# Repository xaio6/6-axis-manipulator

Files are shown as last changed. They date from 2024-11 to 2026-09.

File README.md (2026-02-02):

 # 听懂人话的6轴Agent机械臂（H1）

<h1 align="center">3D打印版本</h1>

## 简介
<div align="center">
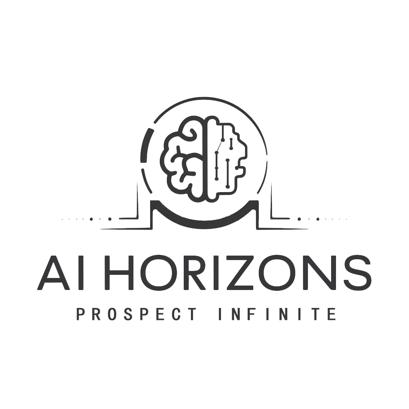
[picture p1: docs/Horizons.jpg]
<br>
</div>

> [!IMPORTANT]
>
> 🔆 该项目也在持续的更新阶段，如果您有任何关于新的模型方法、研究、技术或发现运行错误的建议，请随时编辑并提交 PR。⭐ 如果您发现这个Github Project有用，请给它点个星！🤩🤩

# 控制源码

> 全部源码跟算法在这个[仓库](https://github.com/xaio6/Embodied_Arm)

### 注意事项
- 具体组装跟控制流程，请详细阅读[机械臂组装流程.pdf](./机械臂组装流程-新.pdf)

## 演示

具体演示查看[bilbil](https://www.bilibili.com/video/BV12sSEBQEbQ/?spm_id_from=333.1387.homepage.video_card.click)

<div align="center">
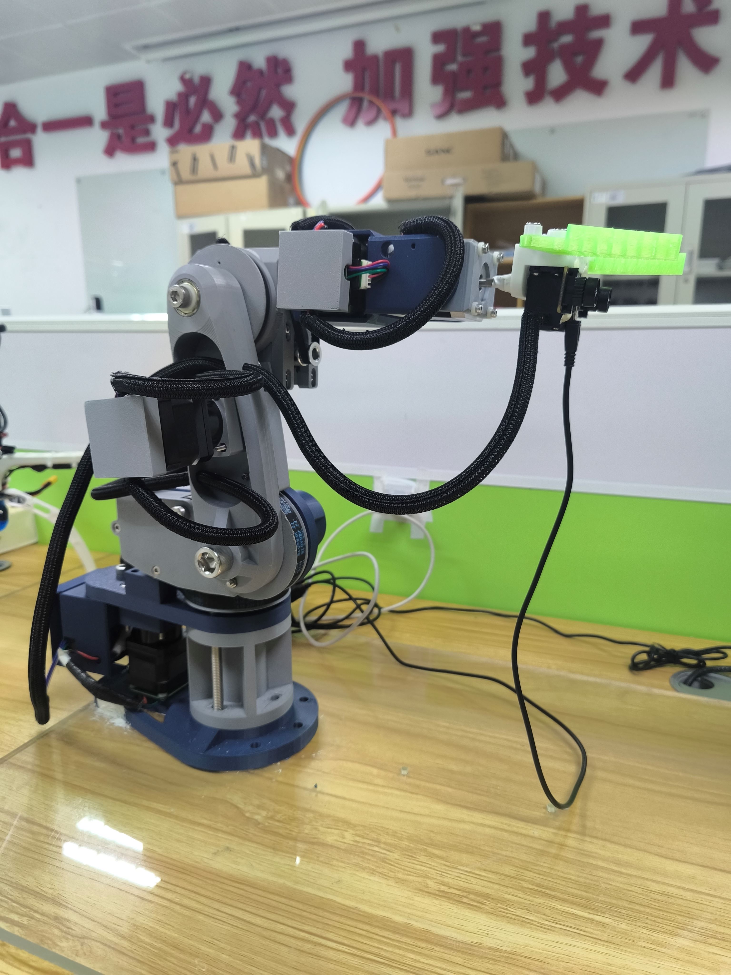
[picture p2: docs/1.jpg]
<br>
</div>

<div align="center">
<br>
</div>

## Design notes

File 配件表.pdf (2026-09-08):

# 机械臂链接螺丝螺母轴承基本配件

对应店铺 (https://item.taobao.com/item.htm?ft=t&id=909249087823&spm=a21dvs.23580594.0.0.4fee2c1bhwSzJX)

### M14 规格

种类 | 规格 | 数量 | 备注

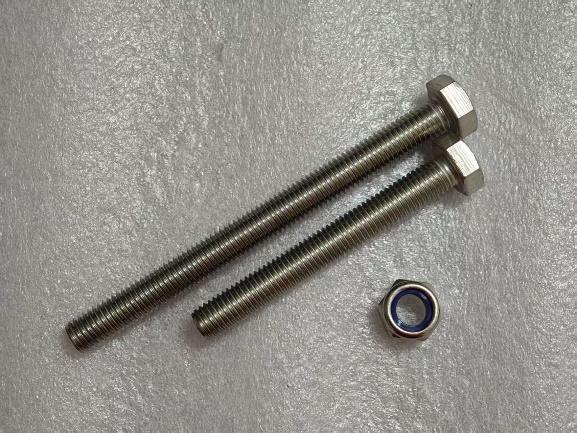
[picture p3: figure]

M14 螺丝(外六角) | 160MM | 1 | 基座之间链接
| 110MM | 1 | 2 座与 3 座之间 链接
M14 螺母 | 带防滑 | 2

### M8 规格

M8 螺丝(内六角) | 100MM | 4 | 基座之间连接
| 35MM | 2 | 2 轴盖子连接跟 电源仓
| 90MM | 1 | 3 轴座与 4 轴座 之间链接
| 80MM | 1 | 4 轴座与 5 轴座 之间链接
M8 螺母 | 加厚 | 8

### M4 规格

M4 螺丝(内六角) | 35MM | 8 | 1 轴和 2 轴减速 器连接块与轴 座之间连接
| 22mm | 4 | 2 轴基座与 2 轴 齿轮之间连接

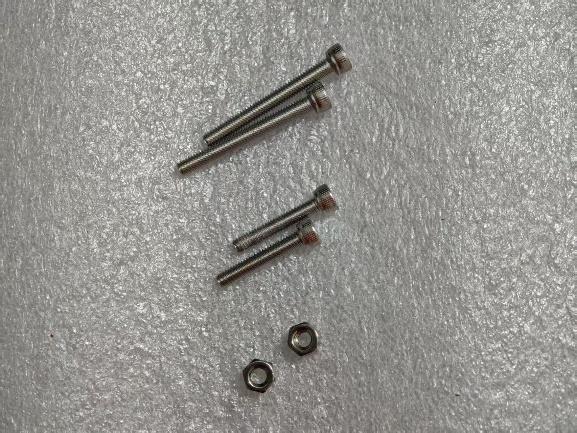
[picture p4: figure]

M4 螺母 | 加厚 | 12

### M3 规格

M3 螺丝(内六角) | 35MM | 36 | 3 轴和 4 轴和 5 轴减速器连接 块与轴座之间 连接
| 8MM | 24 | 减速器与连接 块之间连接以 及末端电机连 接
| 25MM | 4 | 一轴压同步带 块固定
| 15MM | 2 | 一轴压同步带 块固定
M3 螺母 | 加厚 | 42

### 塑料垫片

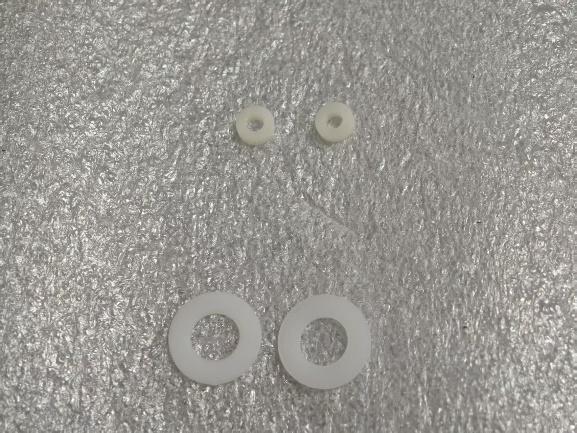
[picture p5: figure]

ABS 垫高柱 | M3*7*1（或者 M3*7*2） | 24 | 一轴压同步带 块轴承垫片以 及驱动板跟电 机连接处
塑胶尼龙垫片 | M8*16*1.5 | 4 | 轴承之间垫片

轴承

轴承 | 623zz | 4

一轴压同步带
块所需

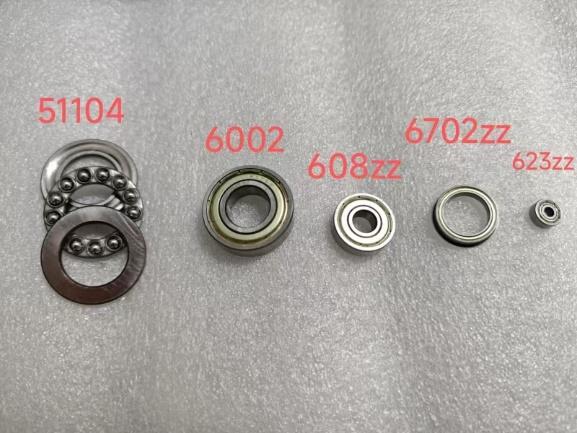
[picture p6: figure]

608zz | 8
6702zz | 3
6002 | 4
51104 | 2

# 电机所需配件

### 同步轮

种类 | 规格 | 数量 | 备注
同步轮 | 2gt、齿 20、宽 6、内孔 8 | 3 | 3 轴 4 轴 5 轴同 步带轮
| 3M、齿 16、宽 10、孔 8 | 2 | 1，2 轴同步带 轮

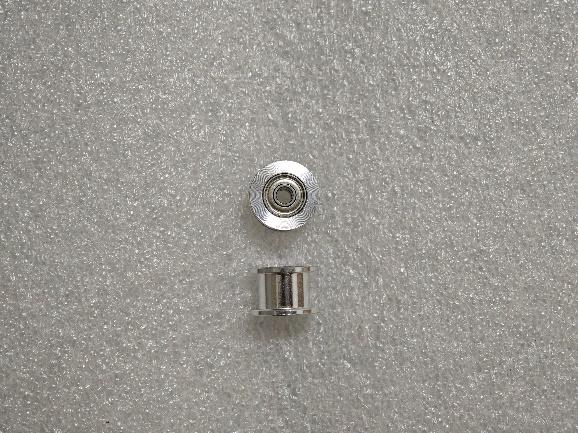
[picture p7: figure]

| 2gt、惰轮、宽 6、齿 16(无齿) | 2 | 盖子与 3 轴连杆 之间

### 同步带

同步带 | 3M、宽 10、长 315 | 1 | 1 轴同步带

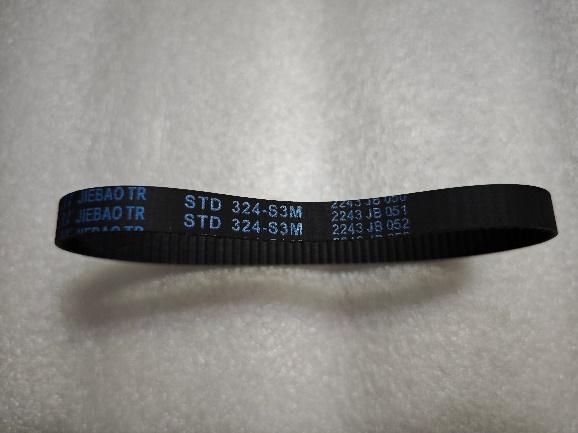
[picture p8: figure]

| 3M、宽 10、长 324 | 1 | 2 轴同步带

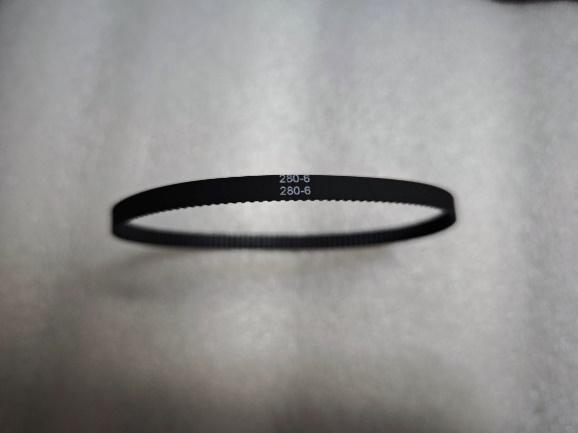
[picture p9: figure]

| 2gt、宽 6、长 280 | 1 | 3 轴同步带
| 2gt、宽 6、长 180(或者 174） | 1 | 4 轴同步带

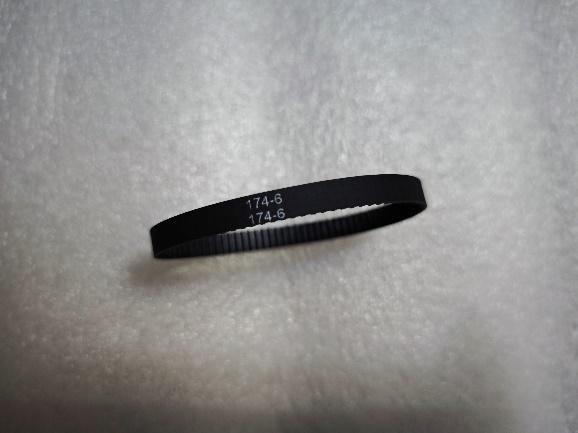
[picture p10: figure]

2gt、宽 6、长
176(或者 174）
1 | 5 轴同步带

### 电机配件

径向磁铁 | 直径 4 高度 4 | 6

### 磁编码器所 需磁铁

电机

种类 | 规格 | 型号 | 备注

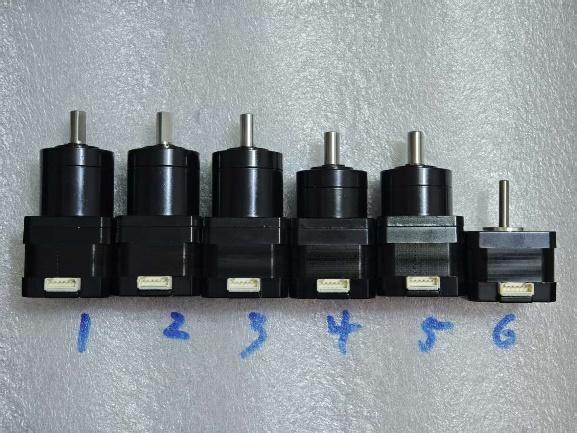
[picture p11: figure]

一轴 | 1:27 | 42HS34 | 一轴
二轴 | 1:27 | 42HS34 | 二轴
三轴 | 1:14 | 42HS34 | 三轴
四轴 | 5.18:1 | 42HS34 | 四轴
五轴 | 5.18:1 | 42HS34 | 五轴
六轴 | 34 高度 | 42BYGHS34S | 六轴

# 电机驱动

种类 | 规格 | 数量 | 备注

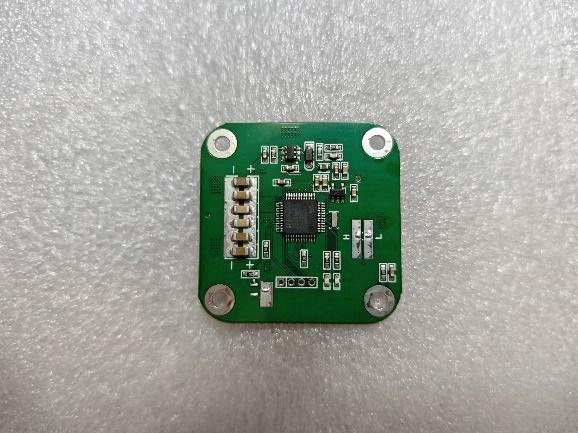
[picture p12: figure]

CAN 闭环步进驱动板 | 12V | 6 | 建议多买一块
USB 转 CAN 板 | | 1

电源

种类 | 规格 | 数量 | 备注

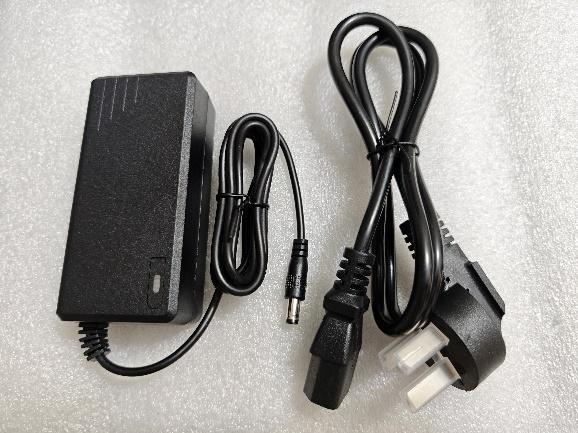
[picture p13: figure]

12V3A 稳定电源 | 12V3A | 1

母头线 | DC 单母头线 | 1

# 视觉抓取

种类 | 规格 | 数量 | 备注

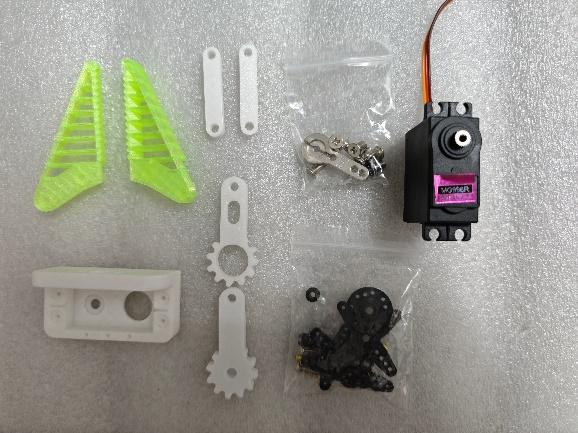
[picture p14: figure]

机械臂柔性软夹子 | | 1 | 机械臂柔性软夹 子

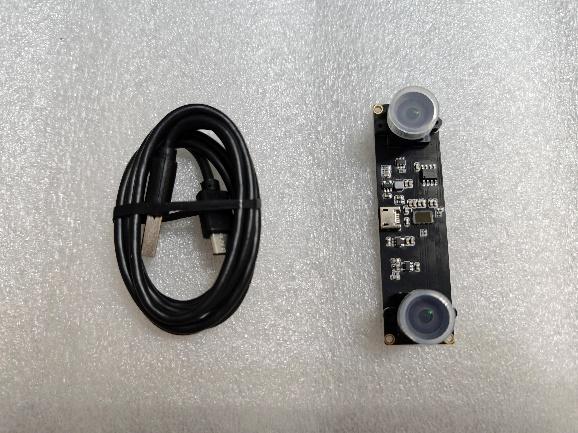
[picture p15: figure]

100 万像素双目相机 | 105°无畸变 /2.4mm | 1 | 100 万像素双目 相机

ESP32 | 带 5V 针脚 | 1 | 最好 type-c 口

# 3D 打印模型外壳

## 有提供 sw 模型，可以自行进行打印

对应店铺 (https://item.taobao.com/item.htm?ft=t&id=909249087823&spm=a21dvs.23580594.0.0.4fee2c1bhwSzJX)

名称 | 数量件/套

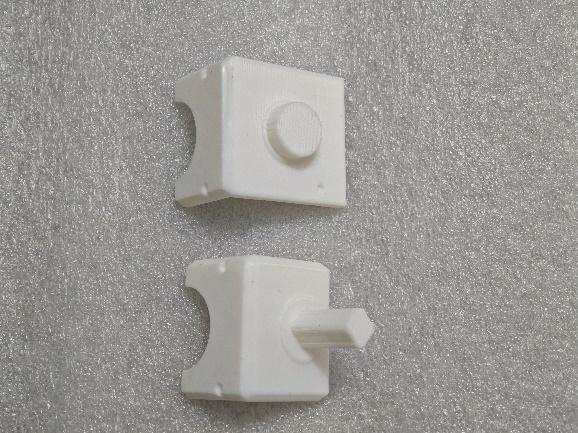
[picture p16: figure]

42_J6_kotelo | 1
Pulley32TGT2 | 1

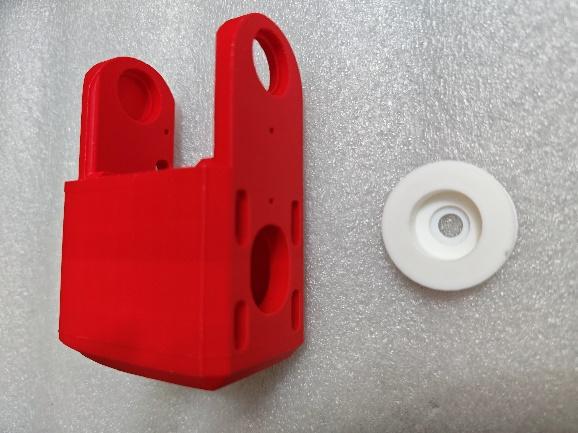
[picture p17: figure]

42 末端 Pulley60Tv2 | 1

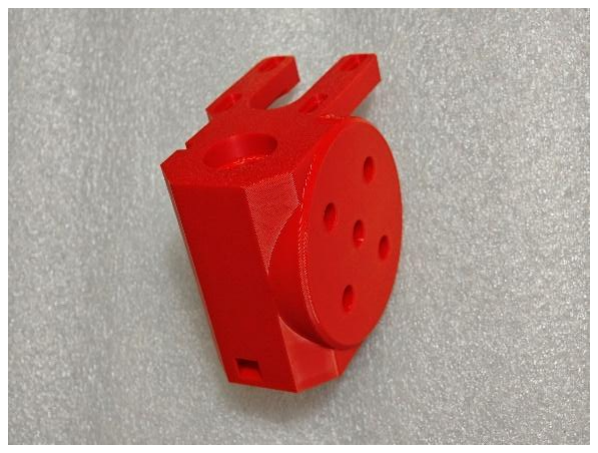
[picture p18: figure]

Arm2Mountv2 | 1
Pulley100Tv5 | 1

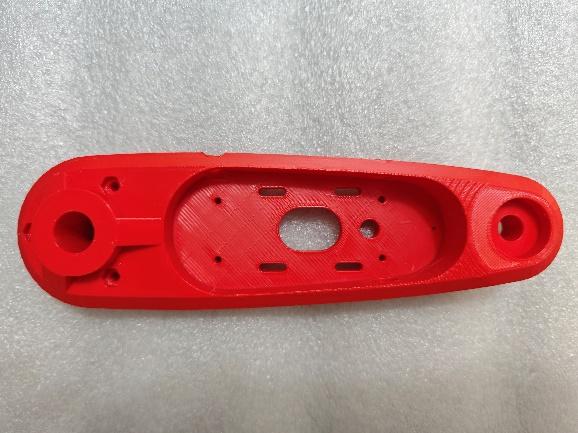
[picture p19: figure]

Arm1v2 | 1

Arm 2.3 | 1

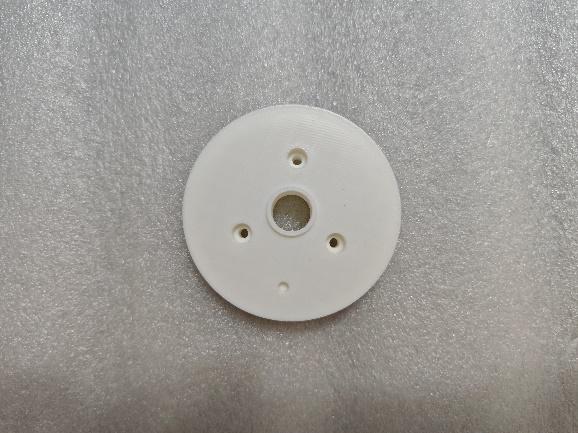
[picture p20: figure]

HTD3M 80T | 1

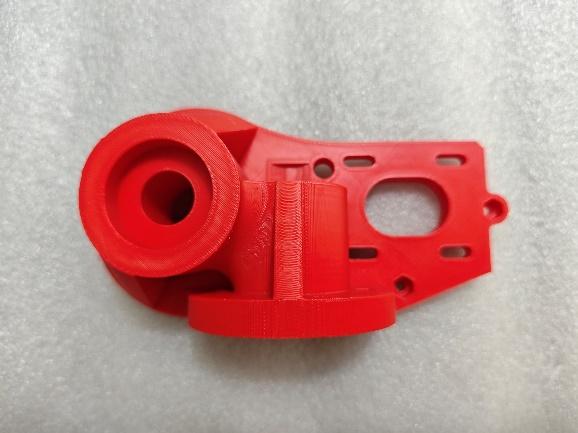
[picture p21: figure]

BaseWall_2_v2 | 1
Basewall cover v2 | 1

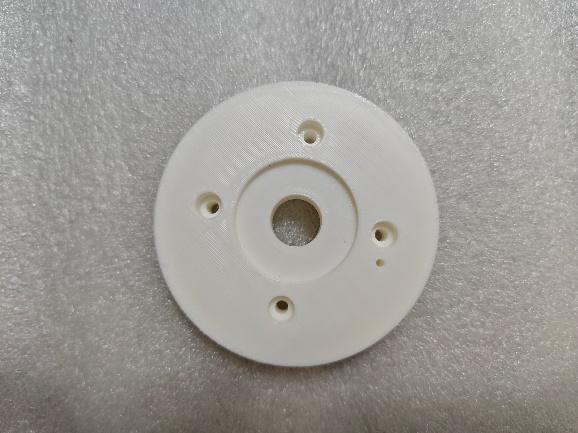
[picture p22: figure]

HTD3M 80T_base | 1
Baseplate | 1

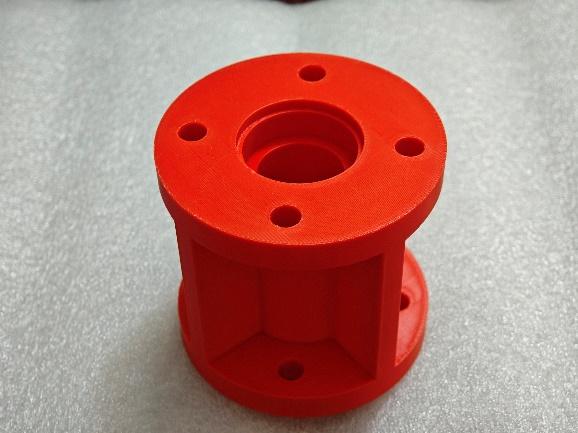
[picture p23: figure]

Bottom Tube | 1

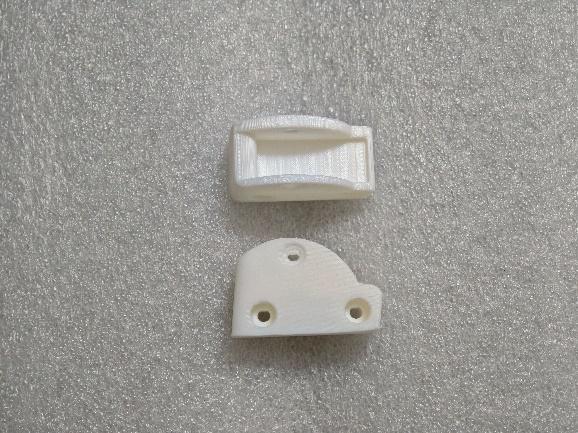
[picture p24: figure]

压同步轮带盖 | 1

Bottom support | 1

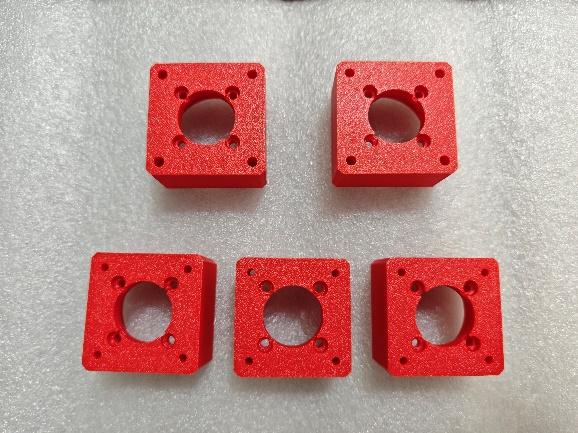
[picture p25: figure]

Motor spacer | 1
电机后盖 | 1

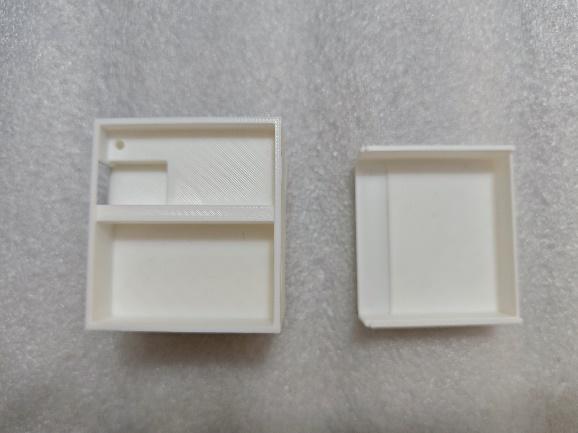
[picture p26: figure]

电源仓 | 1

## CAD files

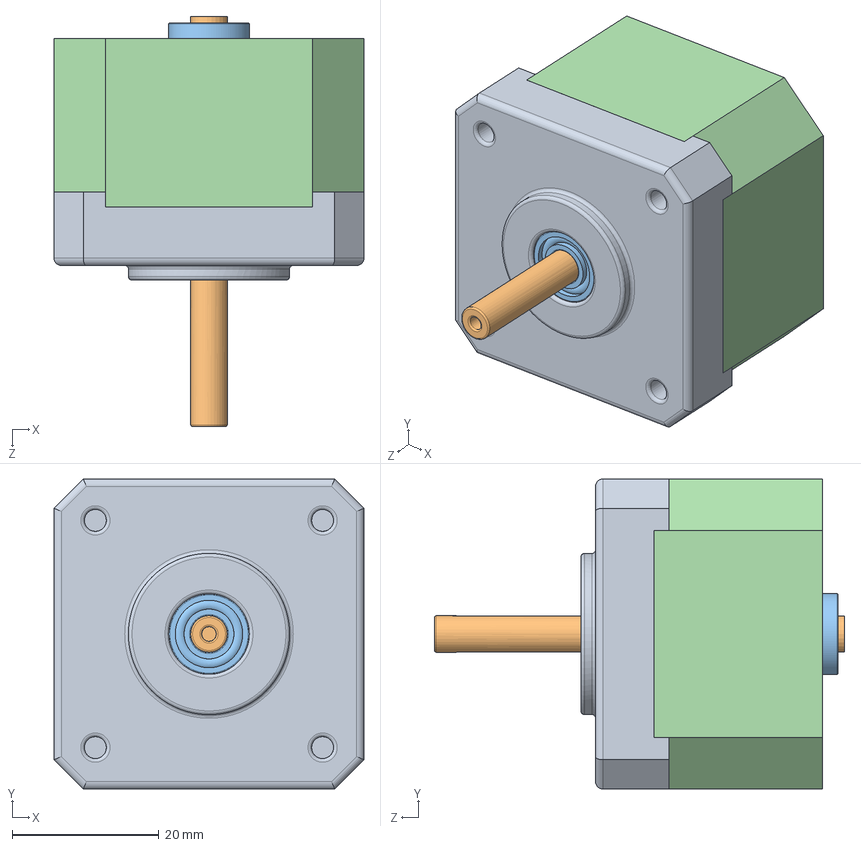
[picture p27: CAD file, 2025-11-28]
Arm_Model/stepper-motor-nema-17.snapshot.17/NEMA 17 kiinalaiset.SLDASM
42.3 x 42.3 x 56.0 mm
Tapa
Eje
instrument ball bearing_68_am x 2
零件2^NEMA 17 kiinalaiset

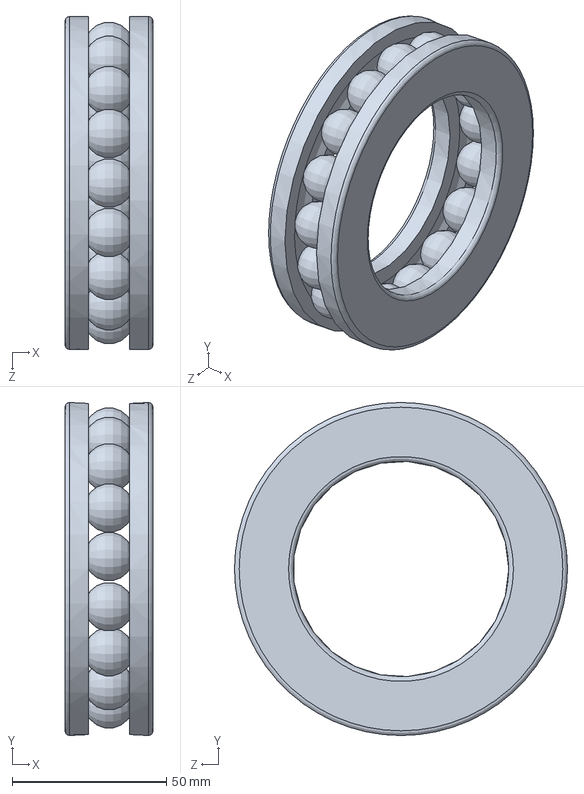
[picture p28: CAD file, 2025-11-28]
Arm_Model/ball bearings/thrust ball bearing_68_iso.sldprt
28.6 x 108.0 x 108.0 mm

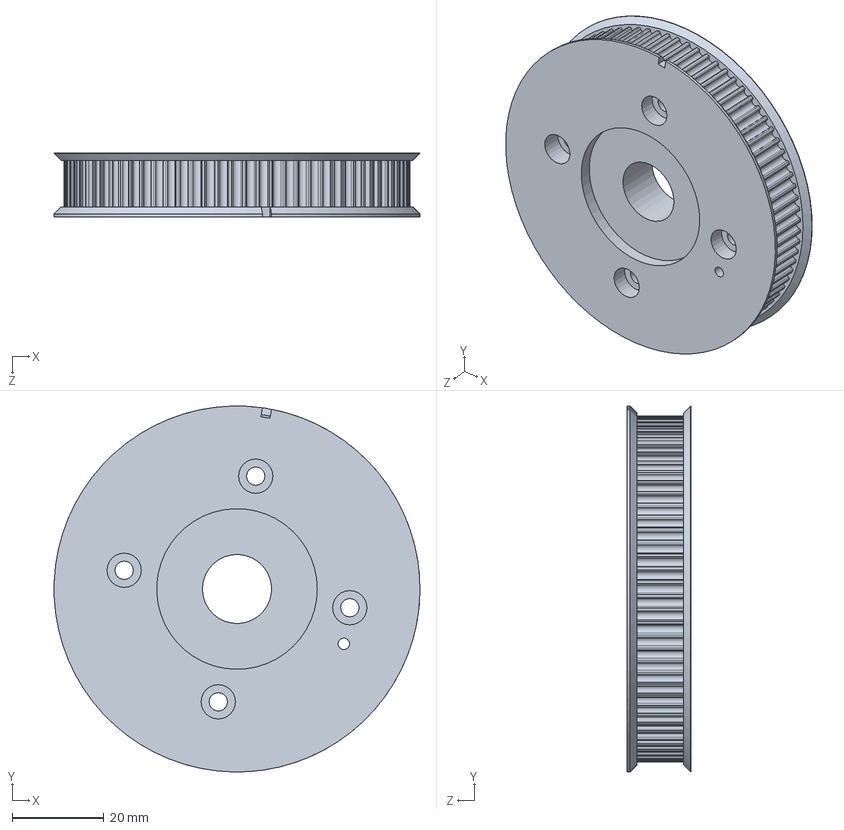
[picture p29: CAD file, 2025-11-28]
Arm_Model/Solidworks/HTD3M 80T_base.SLDPRT
80.0 x 80.0 x 14.0 mm

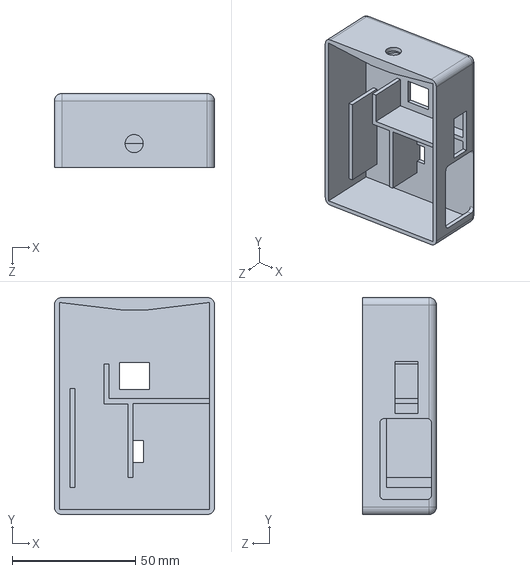
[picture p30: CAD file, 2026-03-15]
Arm_Model/后仓.SLDPRT
65.0 x 88.0 x 30.0 mm

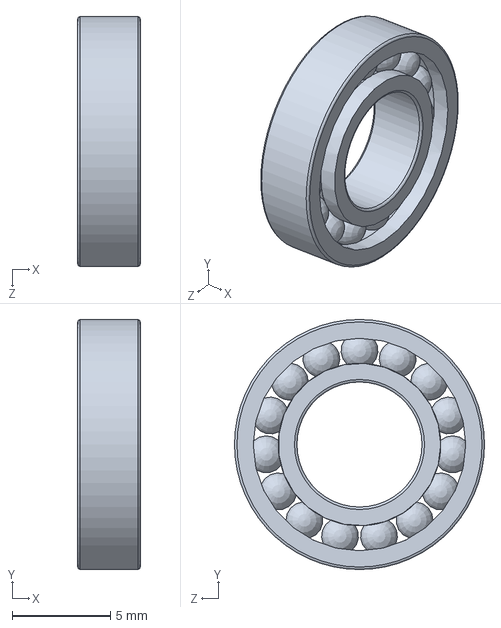
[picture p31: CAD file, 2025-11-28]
Arm_Model/ball bearings/instrument ball bearing_68_am.sldprt
3.17 x 12.7 x 12.7 mm

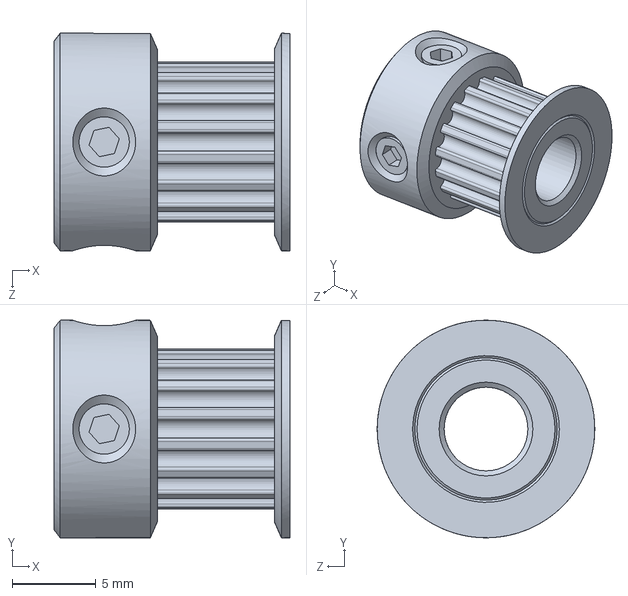
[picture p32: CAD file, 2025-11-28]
Arm_Model/Solidworks/GT2_16T_13x14.SLDPRT
14.1 x 13.0 x 13.0 mm

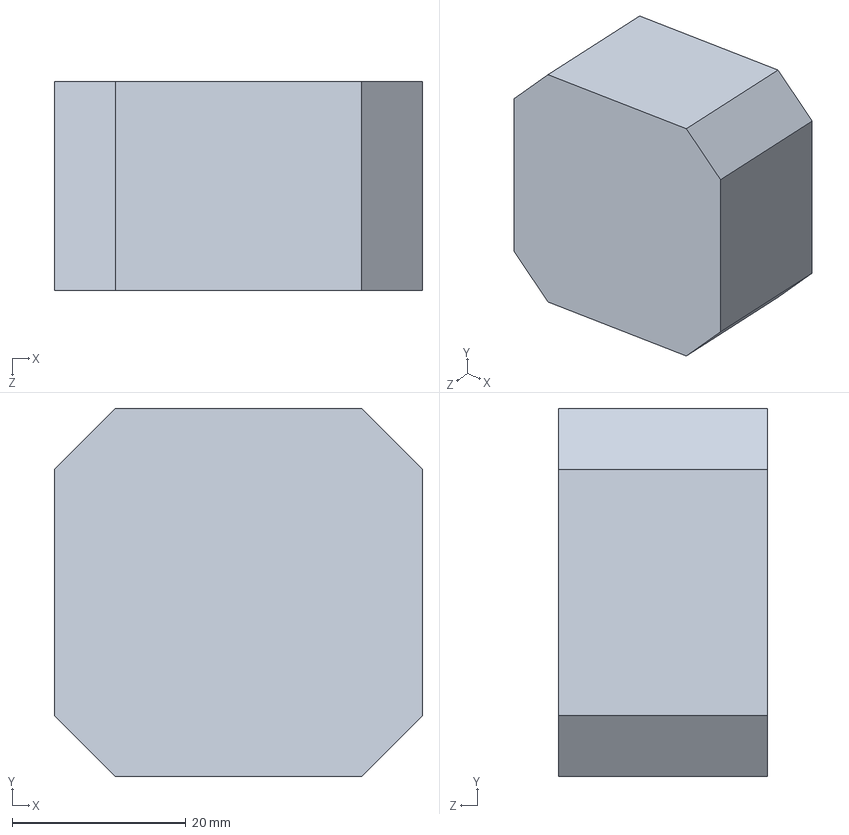
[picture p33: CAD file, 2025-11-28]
Arm_Model/stepper-motor-nema-17.snapshot.17/Cuerpo.SLDPRT
42.3 x 42.3 x 24.0 mm

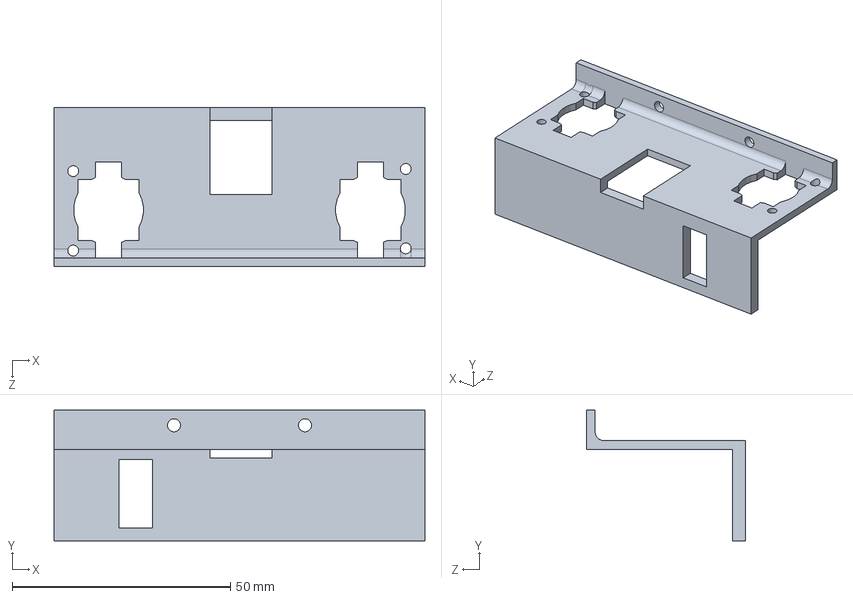
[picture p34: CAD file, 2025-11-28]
Arm_Model/前脸.SLDPRT
85.0 x 30.0 x 36.5 mm

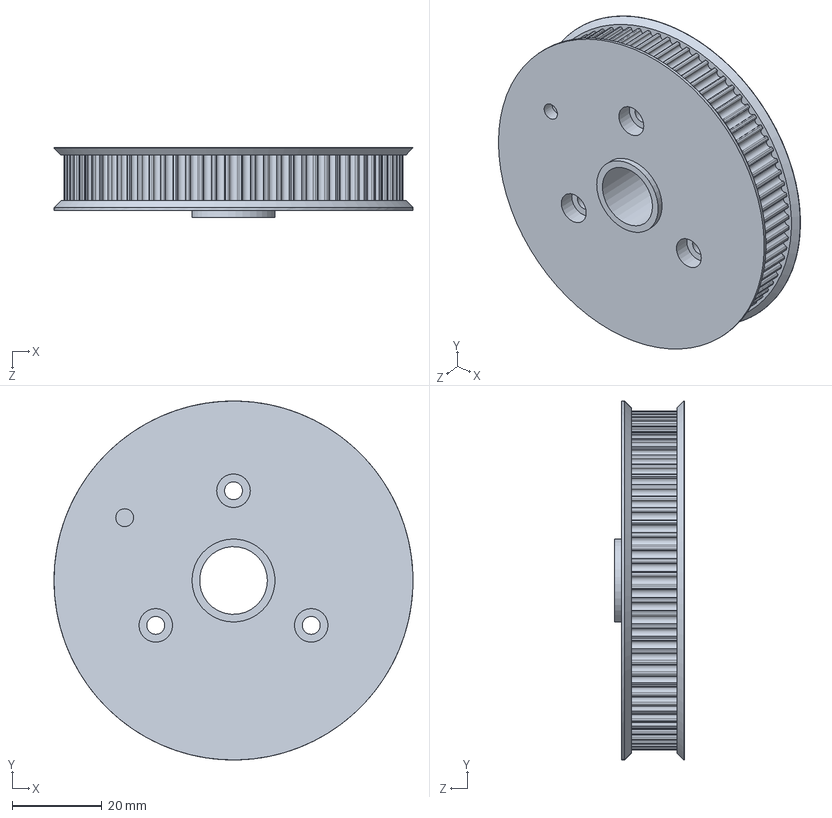
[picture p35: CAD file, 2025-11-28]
Arm_Model/Solidworks/HTD3M 80T.SLDPRT
80.0 x 80.0 x 15.5 mm

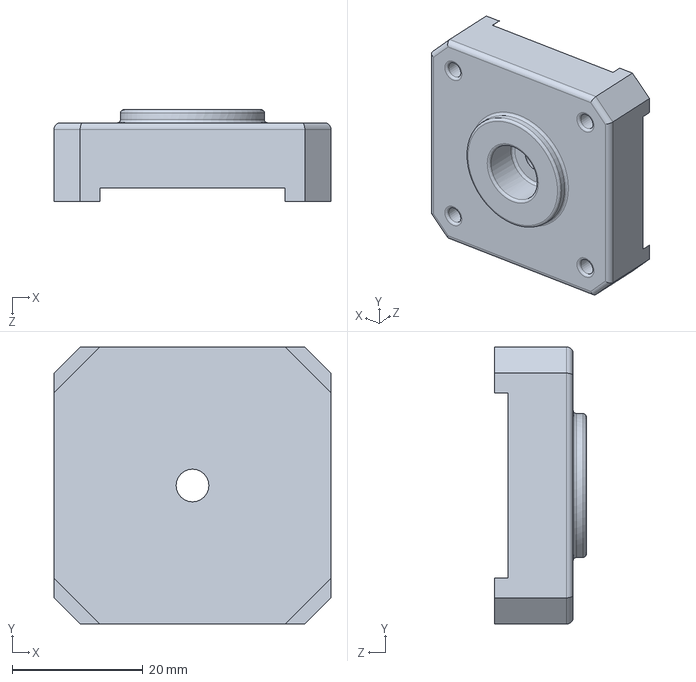
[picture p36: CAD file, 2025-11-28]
Arm_Model/stepper-motor-nema-17.snapshot.17/Tapa.SLDPRT
42.3 x 42.3 x 14.0 mm

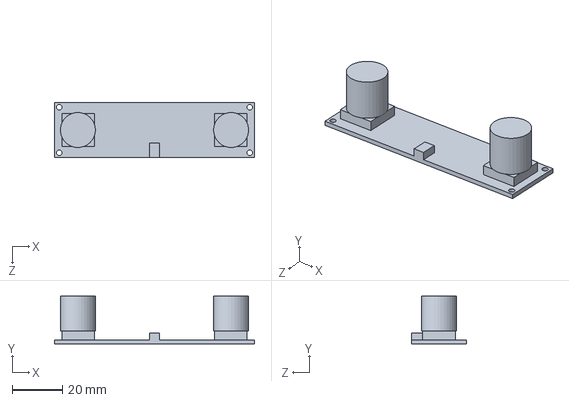
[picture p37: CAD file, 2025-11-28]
Arm_Model/相机.SLDPRT
80.0 x 19.1 x 22.0 mm

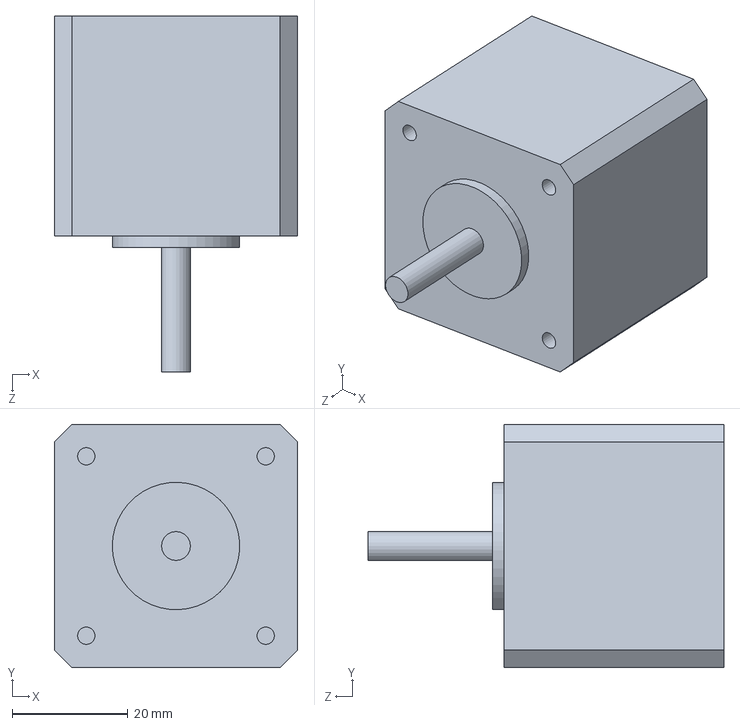
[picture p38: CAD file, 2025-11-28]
Arm_Model/Solidworks/Nema 14 stepper.SLDPRT
42.0 x 42.0 x 61.5 mm

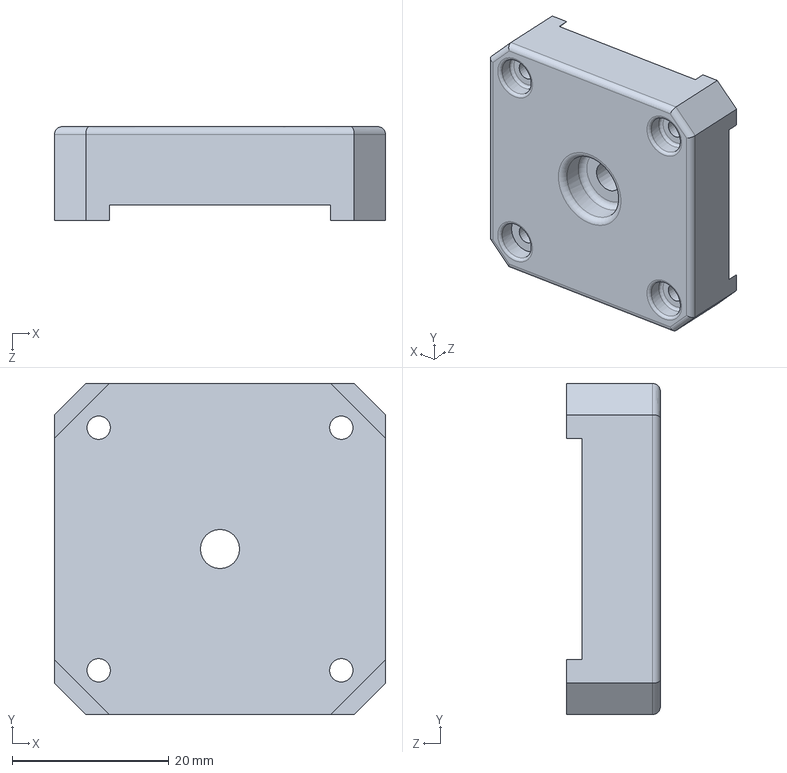
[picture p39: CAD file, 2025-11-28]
Arm_Model/stepper-motor-nema-17.snapshot.17/Base.SLDPRT
42.3 x 42.3 x 12.0 mm

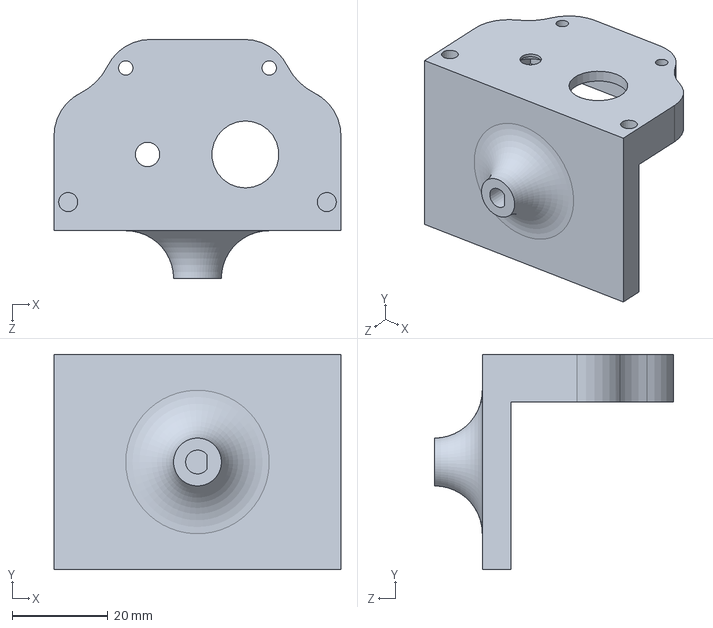
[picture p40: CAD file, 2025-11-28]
Arm_Model/夹爪主体.SLDPRT
60.0 x 45.0 x 50.0 mm

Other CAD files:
Arm_Model/Assem4_v2.SLDASM
Arm_Model/ball bearings/angular contact ball bearing_68_iso.sldprt
Arm_Model/GT2_5_20齿.SLDPRT
Arm_Model/15mm 1.6 rikka.SLDPRT
Arm_Model/15mm rikka 1.2mm.SLDPRT
Arm_Model/3M HTD 16T 6mm Bore.SLDPRT
Arm_Model/42_J6_kotelo_1.SLDPRT
Arm_Model/42_J6_kotelo_2.SLDPRT
Arm_Model/42末端Pulley60Tv2.SLDPRT
Arm_Model/6轴配件.SLDPRT
Arm_Model/Arm 2.3.SLDPRT
Arm_Model/Arm1v2.SLDPRT
Arm_Model/Arm2Mountv2.SLDPRT
Arm_Model/BaseWall_2_v2.SLDPRT
Arm_Model/Baseplate.SLDPRT
Arm_Model/Basewall cover v2.SLDPRT
Arm_Model/Bottom Tube.SLDPRT
Arm_Model/Bottom support.SLDPRT
Arm_Model/M14-110mm.SLDPRT
Arm_Model/M14-140mm.SLDPRT
Arm_Model/M14-150mm.SLDPRT
Arm_Model/M14.SLDPRT
Arm_Model/M8-40mm - Copy.SLDPRT
Arm_Model/Motor1 spacer.SLDPRT
Arm_Model/Motor3 spacer .SLDPRT
Arm_Model/Nema 17 planetary 5 to 1 gearbox.SLDPRT
Arm_Model/Nema8 Stepperi (banggood.com).SLDPRT
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

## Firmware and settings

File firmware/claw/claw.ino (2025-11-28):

#include <ESP32Servo.h>

Servo myservo;

void setup() {
  // put your setup code here, to run once:
  Serial.begin(9600);  // 初始化串口通信速率
  myservo.attach(3);
}

void loop() {
  // put your main code here, to run repeatedly:
  if (Serial.available()) {
    int angle = Serial.parseInt();
    // 丢弃后续的换行/回车，避免下一次parseInt等待超时返回0
    while (Serial.peek() == '\n' || Serial.peek() == '\r') {
      Serial.read();
    }
    if (angle >= 0 && angle <= 180) {
      myservo.write(angle);
    }
  }
}
